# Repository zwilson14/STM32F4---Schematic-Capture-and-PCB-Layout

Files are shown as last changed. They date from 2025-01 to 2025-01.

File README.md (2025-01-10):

# STM32F4---Schematic-Capture-and-PCB-Layout
Schematic Capture and PCB Layout of a STM32F4 based microcontroller. Four layer board utilizing KiCAD w/ USB, I2C, and USART headers.
Used KiCAD for the schematic capture and board layout, and STM32CubeIDE to do the I/O planning and pin mapping.

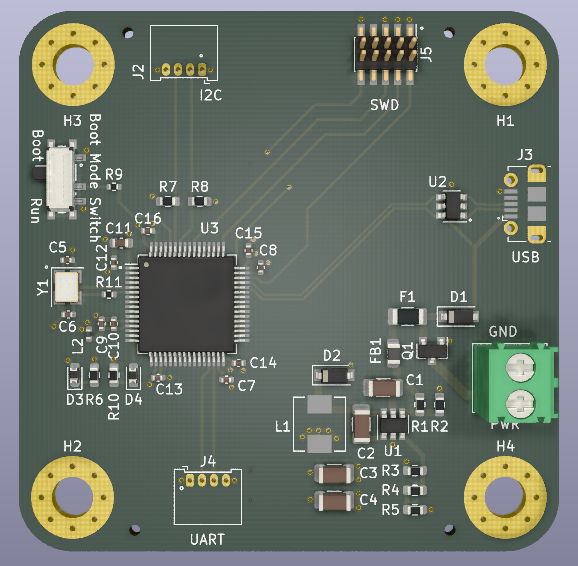
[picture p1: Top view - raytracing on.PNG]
Project Icon


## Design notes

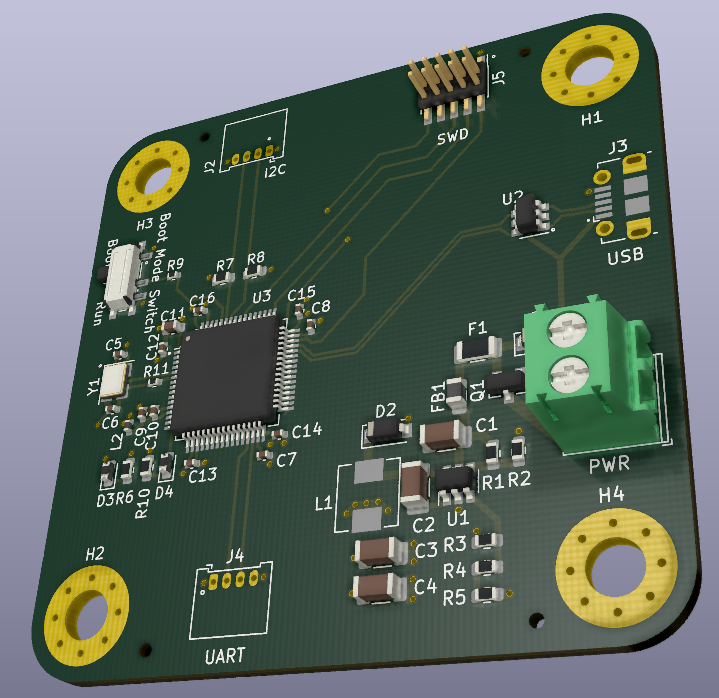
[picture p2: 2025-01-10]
ISO of top, raytracing on.PNG

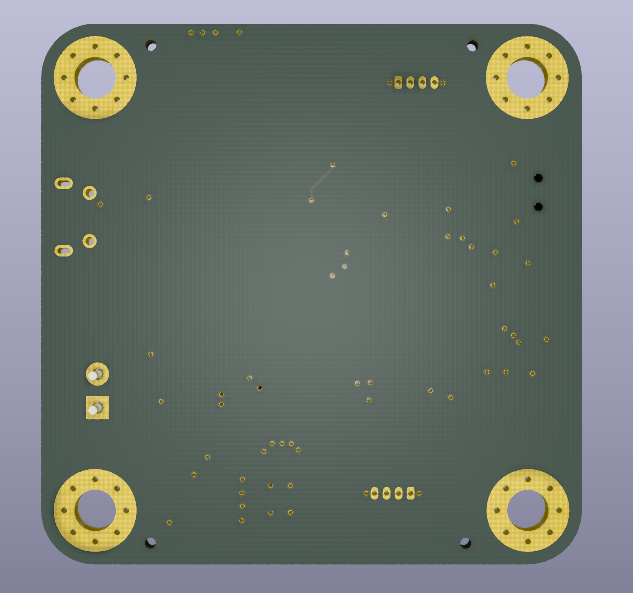
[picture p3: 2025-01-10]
Bottom - raytracing on.PNG

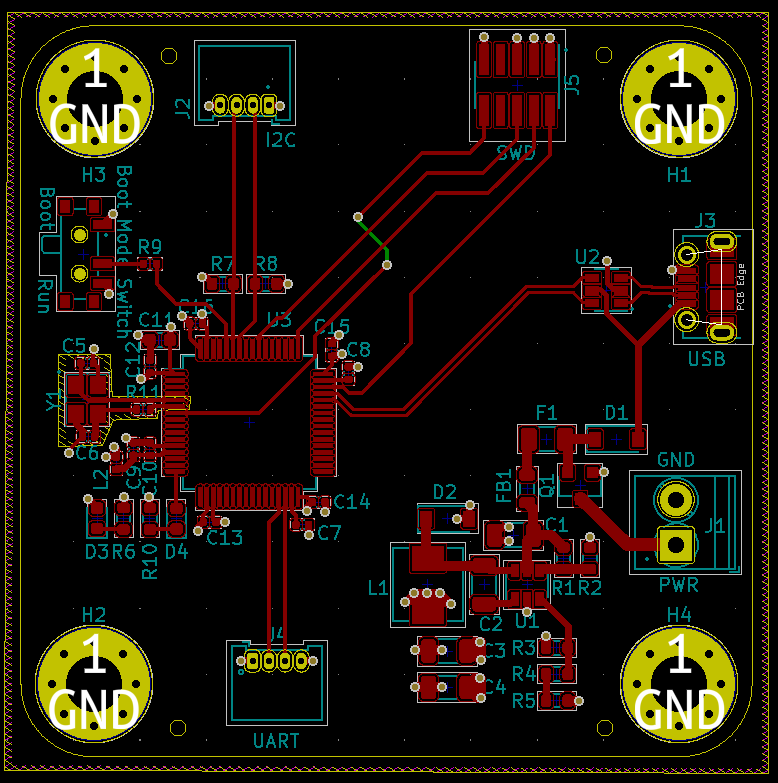
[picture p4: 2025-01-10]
Basic routing.PNG

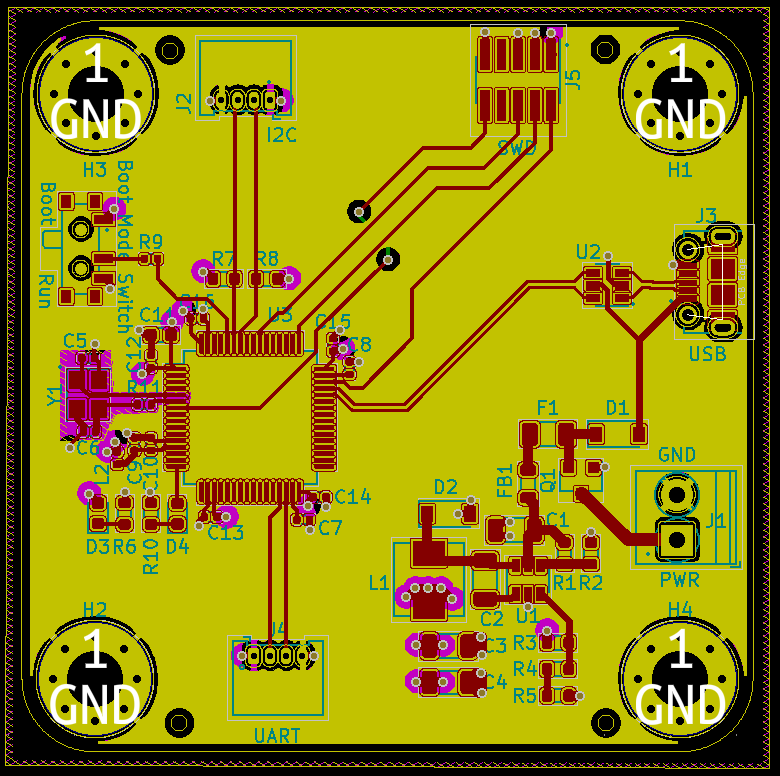
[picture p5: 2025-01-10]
copper pours showing.PNG

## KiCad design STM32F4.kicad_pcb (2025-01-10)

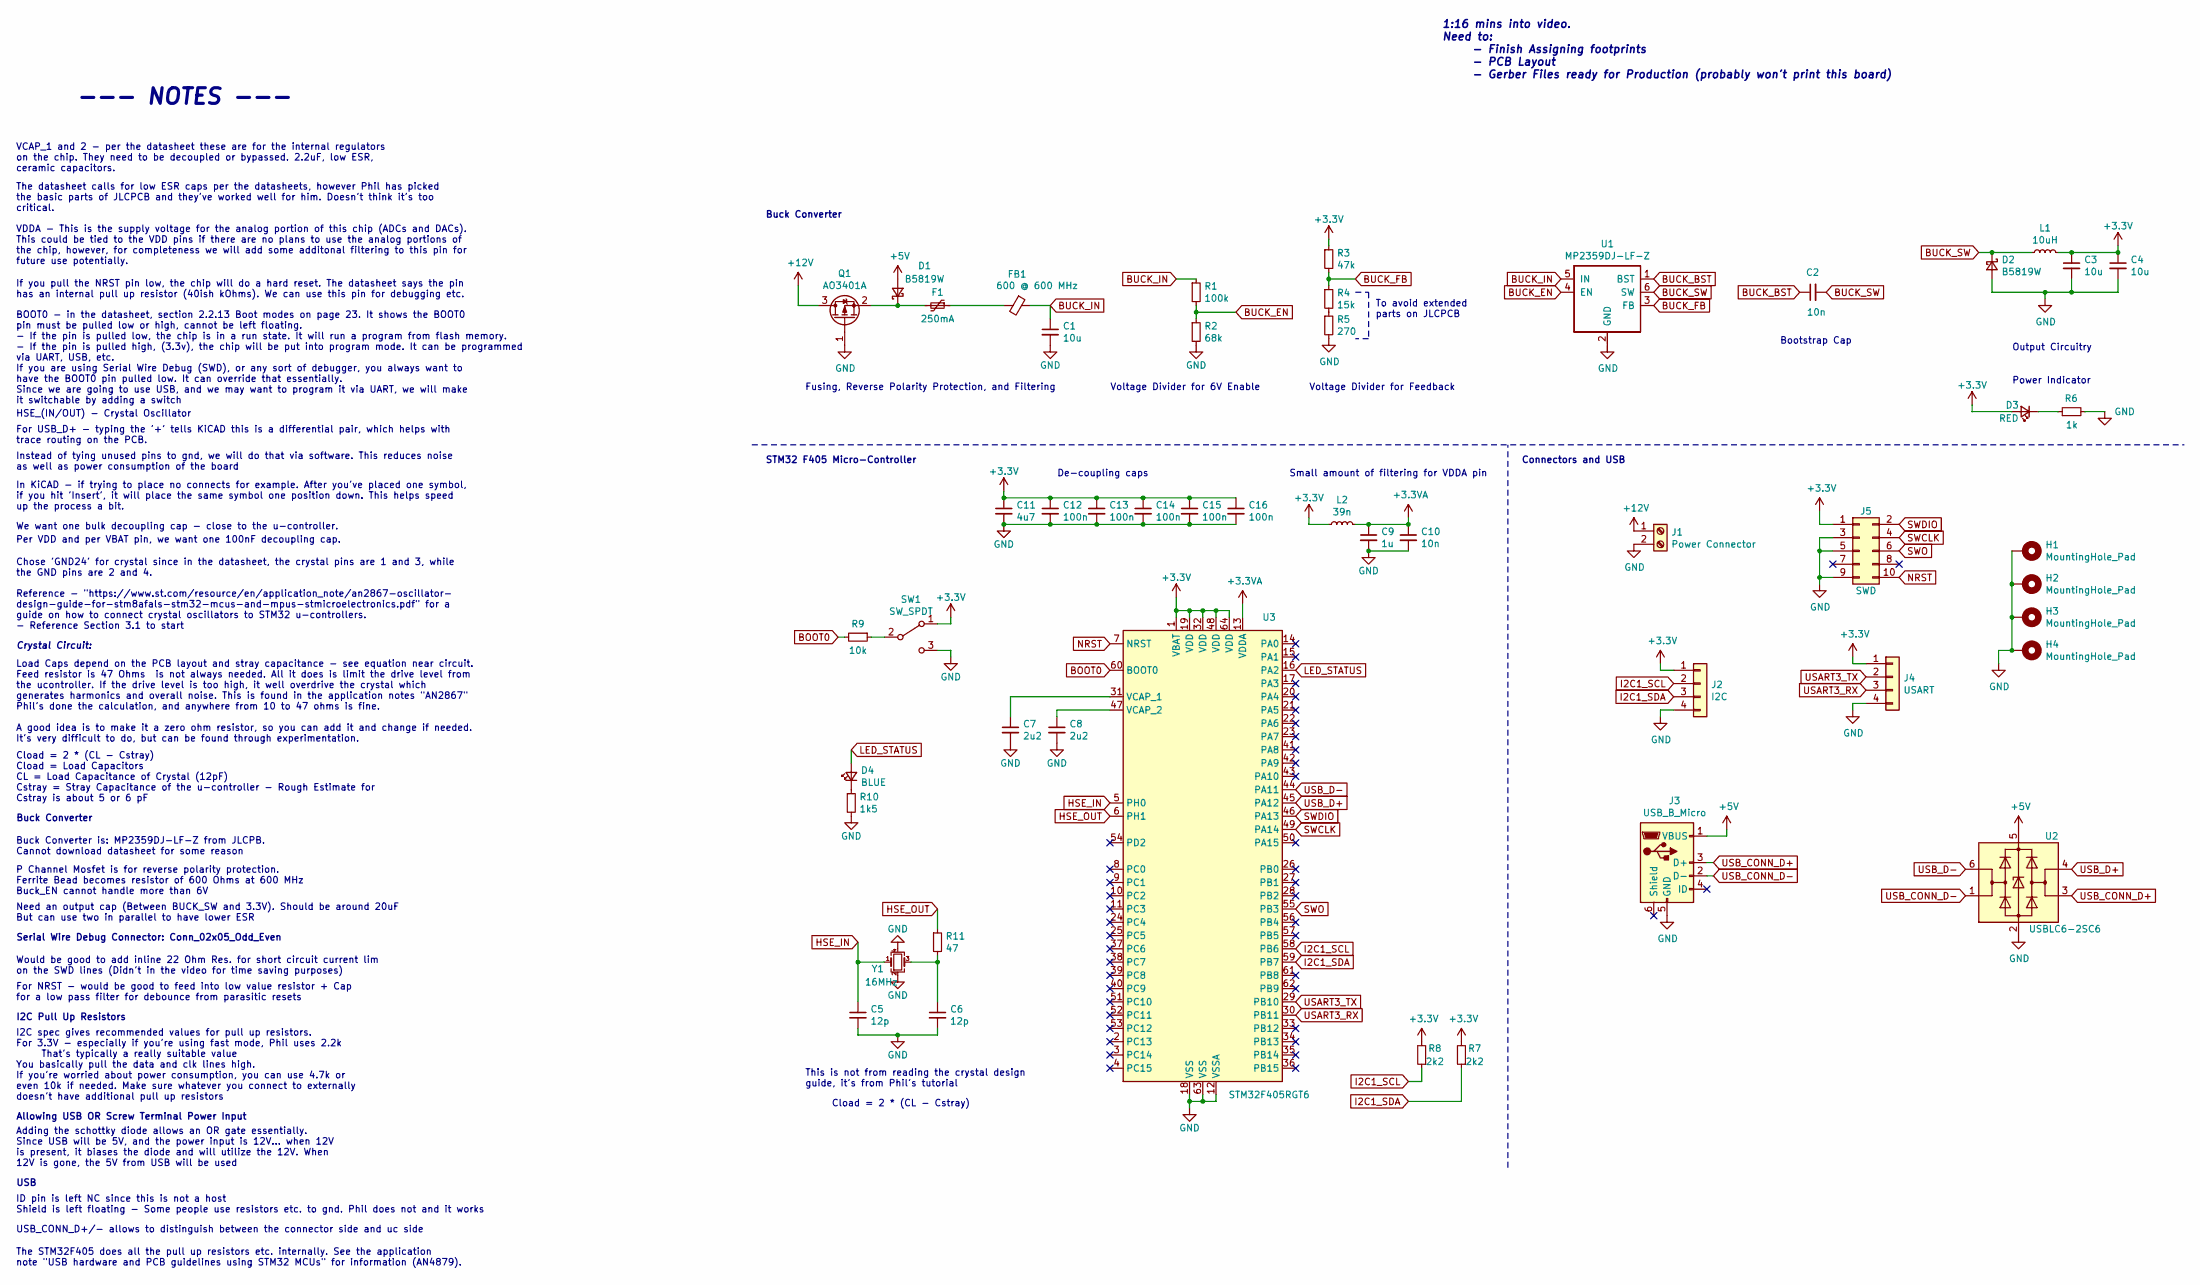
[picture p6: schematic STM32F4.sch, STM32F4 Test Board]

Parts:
C1, C3, C4: 10u; C_1206_3216Metric
C2: 10n; C_1206_3216Metric
C5, C6: 12p; C_0402_1005Metric
C7, C8: 2u2; C_0402_1005Metric
C9: 1u; C_0402_1005Metric
C10: 10n; C_0402_1005Metric
C11: 4u7; C_0603_1608Metric
C12, C13, C14, C15, C16: 100n; C_0402_1005Metric
D1, D2: B5819W; D_SOD-123
D3: RED; D_0603_1608Metric
D4: BLUE; D_0603_1608Metric
F1: 250mA; Fuse_1206_3216Metric
FB1: 600 @ 600 MHz; L_0805_2012Metric
H1, H2, H3, H4: MountingHole_Pad; MountingHole_4.3mm_M4_Pad_Via
J1: Power Connector; TerminalBlock_Phoenix_PT-1,5-2-3.5-H_1x02_P3.50mm_Horizontal
J2: I2C; Molex_PicoBlade_53048-0410_1x04_P1.25mm_Horizontal
J3: USB_B_Micro; USB_Micro-B_Molex-105017-0001
J4: USART; Molex_PicoBlade_53048-0410_1x04_P1.25mm_Horizontal
J5: SWD; PinHeader_2x05_P1.27mm_Vertical_SMD
L1: 10uH; L_Sunlord_MWSA0518_5.4x5.2mm
L2: 39n; L_0402_1005Metric
Q1: AO3401A; SOT-23
R1: 100k; R_0603_1608Metric
R2: 68k; R_0603_1608Metric
R3: 47k; R_0603_1608Metric
R4: 15k; R_0603_1608Metric
R5: 270; R_0603_1608Metric
R6: 1k; R_0603_1608Metric
R7, R8: 2k2; R_0603_1608Metric
R9: 10k; R_0402_1005Metric
R10: 1k5; R_0603_1608Metric
R11: 47; R_0402_1005Metric
SW1: SW_SPDT; SW_SPDT_PCM12
U1: MP2359DJ-LF-Z; SOT-23-6
U2: USBLC6-2SC6; SOT-23-6
U3: STM32F405RGT6; LQFP-64_10x10mm_P0.5mm
Y1: 16MHz; Crystal_SMD_3225-4Pin_3.2x2.5mm

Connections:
+3.3VA: C9.1, C10.1, L2.2, U3.13 (VDDA)
+3V3: C3.1, C4.1, C11.1, C12.1, C13.1, C14.1, C15.1, C16.1, D3.2 (A), J2.1, J4.1, J5.1, L1.2, L2.1, R3.1, R7.2, R8.2, SW1.1 (A), U3.1 (VBAT), U3.19 (VDD), U3.32 (VDD), U3.48 (VDD), U3.64 (VDD)
+5V: D1.2 (A), J3.1 (VBUS), U2.5 (VBUS)
+12V: J1.1, Q1.3 (D)
BOOT0: R9.2, U3.60 (BOOT0)
BUCK_BST: C2.1, U1.1 (BST)
BUCK_EN: R1.2, R2.1, U1.4 (EN)
BUCK_FB: R3.2, R4.1, U1.3 (FB)
BUCK_IN: C1.1, FB1.1, R1.1, U1.5 (IN)
BUCK_SW: C2.2, D2.1 (K), L1.1, U1.6 (SW)
GND: C1.2, C3.2, C4.2, C5.2, C6.2, C7.2, C8.2, C9.2, C10.2, C11.2, C12.2, C13.2, C14.2, C15.2, C16.2, D2.2 (A), H1.1, H2.1, H3.1, H4.1, J1.2, J2.4, J3.5 (GND), J4.4, J5.3, J5.5, J5.9, Q1.1 (G), R2.2, R5.2, R6.2, R10.2, SW1.3 (C), U1.2 (GND), U2.2 (GND), U3.12 (VSSA), U3.18 (VSS), U3.63 (VSS), Y1.2, Y1.4
HSE_IN: C5.1, U3.5 (PH0), Y1.1
HSE_OUT: R11.1, U3.6 (PH1)
I2C1_SCL: J2.2, R8.1, U3.58 (PB6)
I2C1_SDA: J2.3, R7.1, U3.59 (PB7)
LED_STATUS: D4.2 (A), U3.16 (PA2)
NRST: J5.10, U3.7 (NRST)
unnamed: C6.1, R11.2, Y1.3
unnamed: C7.1, U3.31 (VCAP_1)
unnamed: C8.1, U3.47 (VCAP_2)
unnamed: D1.1 (K), F1.2, Q1.2 (S)
unnamed: D3.1 (K), R6.1
unnamed: D4.1 (K), R10.1
unnamed: F1.1, FB1.2
unnamed: R4.2, R5.1
unnamed: R9.1, SW1.2 (B)
SWCLK: J5.4, U3.49 (PA14)
SWDIO: J5.2, U3.46 (PA13)
SWO: J5.6, U3.55 (PB3)
USART3_RX: J4.3, U3.30 (PB11)
USART3_TX: J4.2, U3.29 (PB10)
USB_CONN_D+: J3.3 (D+), U2.3 (I/O2)
USB_CONN_D-: J3.2 (D-), U2.1 (I/O1)
USB_D+: U2.4 (I/O2), U3.45 (PA12)
USB_D-: U2.6 (I/O1), U3.44 (PA11)

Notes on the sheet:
VDDA - This is the supply voltage for the analog portion of this chip (ADCs and DACs). This could be tied to the VDD pins if there are no plans to use the analog portions of the chip, however, for completeness we will add some additonal filtering to this pin for future use potentially.
VCAP_1 and 2 - per the datasheet these are for the internal regulators on the chip. They need to be decoupled or bypassed. 2.2uF, low ESR, ceramic capacitors.
The datasheet calls for low ESR caps per the datasheets, however Phil has picked the basic parts of JLCPCB and they've worked well for him. Doesn't think it's too critical.
If you pull the NRST pin low, the chip will do a hard reset. The datasheet says the pin has an internal pull up resistor (40ish kOhms). We can use this pin for debugging etc.
HSE_(IN/OUT) - Crystal Oscillator
For USB_D+ - typing the '+' tells KiCAD this is a differential pair, which helps with trace routing on the PCB.
Instead of tying unused pins to gnd, we will do that via software. This reduces noise as well as power consumption of the board
In KiCAD - if trying to place no connects for example. After you've placed one symbol, if you hit 'Insert', it will place the same symbol one position down. This helps speed up the process a bit.
We want one bulk decoupling cap - close to the u-controller.
Per VDD and per VBAT pin, we want one 100nF decoupling cap.
De-coupling caps
Cload = 2 * (CL - Cstray)
Crystal Circuit:
BOOT0 - in the datasheet, section 2.2.13 Boot modes on page 23. It shows the BOOT0 pin must be pulled low or high, cannot be left floating. - If the pin is pulled low, the chip is in a run state. It will run a program from flash memory. - If the pin is pulled high, (3.3v), the chip will be put into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
Small amount of filtering for VDDA pin
STM32 F405 Micro-Controller
Buck Converter
To avoid extended parts on JLCPCB
Fusing, Reverse Polarity Protection, and Filtering
Voltage Divider for 6V Enable
Voltage Divider for Feedback
Bootstrap Cap
Output Circuitry
Would be good to add inline 22 Ohm Res. for short circuit current lim on the SWD lines (Didn't in the video for time saving purposes)
For NRST - would be good to feed into low value resistor + Cap for a low pass filter for debounce from parasitic resets
Serial Wire Debug Connector: Conn_02x05_Odd_Even
Need an output cap (Between BUCK_SW and 3.3V). Should be around 20uF But can use two in parallel to have lower ESR
P Channel Mosfet is for reverse polarity protection. Ferrite Bead becomes resistor of 600 Ohms at 600 MHz Buck_EN cannot handle more than 6V
Buck Converter is: MP2359DJ-LF-Z from JLCPB. Cannot download datasheet for some reason
Load Caps depend on the PCB layout and stray capacitance - see equation near circuit. Feed resistor is 47 Ohms ~ is not always needed. All it does is limit the drive level from the ucontroller. If the drive level is too high, it well overdrive the crystal which generates harmonics and overall noise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
Cload = 2 * (CL - Cstray) Cload = Load Capacitors CL = Load Capacitance of Crystal (12pF) Cstray = Stray Capacitance of the u-controller - Rough Estimate for Cstray is about 5 or 6 pF
This is not from reading the crystal design guide, it's from Phil's tutorial
Reference - "https://www.st.com/resource/en/application_note/an2867-oscillator- design-guide-for-stm8afals-stm32-mcus-and-mpus-stmicroelectronics.pdf" for a guide on how to connect crystal oscillators to STM32 u-controllers. - Reference Section 3.1 to start
Chose 'GND24' for crystal since in the datasheet, the crystal pins are 1 and 3, while the GND pins are 2 and 4.
I2C Pull Up Resistors
I2C spec gives recommended values for pull up resistors. For 3.3V - especially if you're using fast mode, Phil uses 2.2k That's typically a really suitable value You basically pull the data and clk lines high. If you're worried about power consumption, you can use 4.7k or even 10k if needed. Make s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
Allowing USB OR Screw Terminal Power Input
Adding the schottky diode allows an OR gate essentially. Since USB will be 5V, and the power input is 12V... when 12V is present, it biases the diode and will utilize the 12V. When 12V is gone, the 5V from USB will be used
USB
ID pin is left NC since this is not a host Shield is left floating - Some people use resistors etc. to gnd. Phil does not and it works

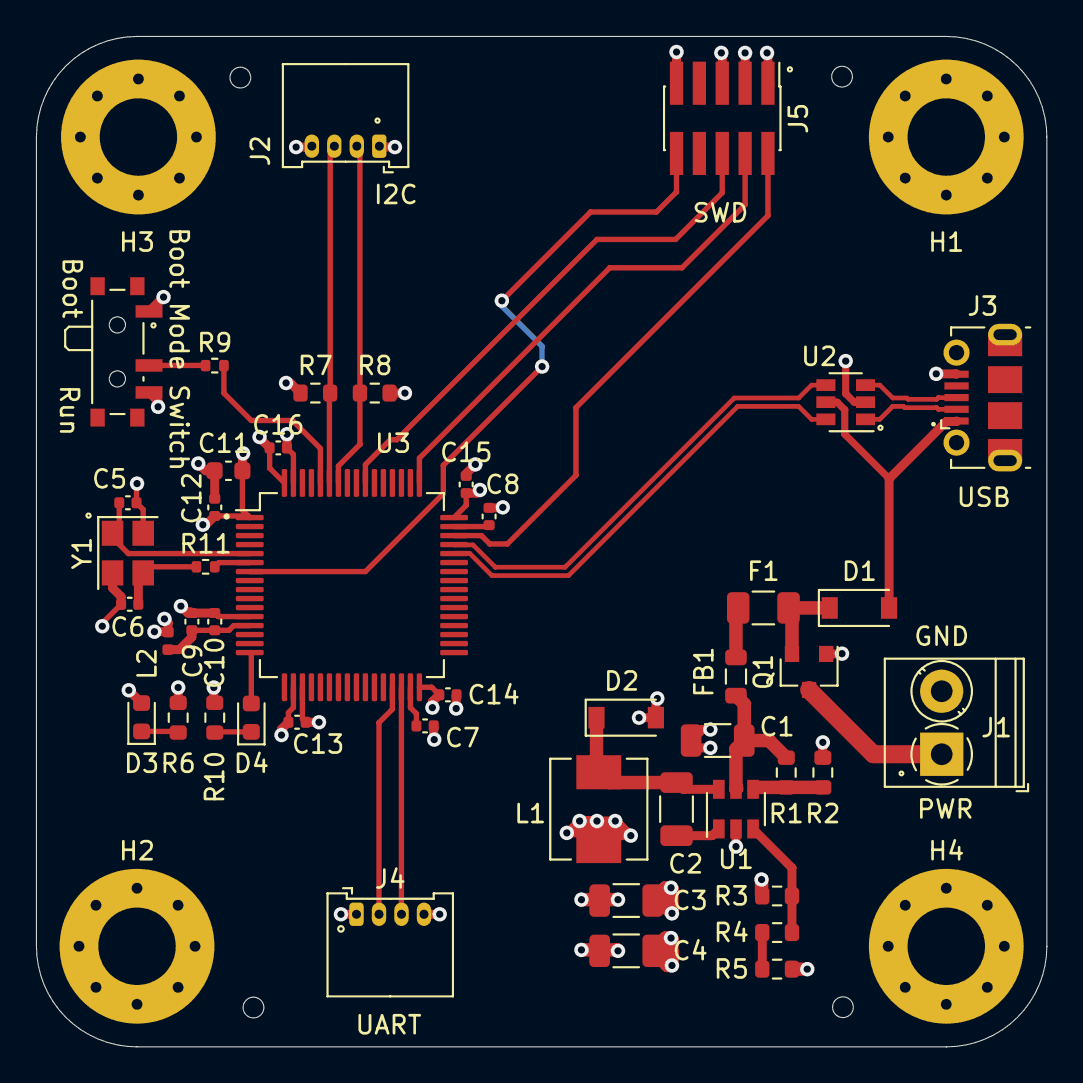
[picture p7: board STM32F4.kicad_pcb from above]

Board: 4 copper layers, 56.1 x 56.1 mm, 50 parts (0 on the bottom side), 35 nets.
